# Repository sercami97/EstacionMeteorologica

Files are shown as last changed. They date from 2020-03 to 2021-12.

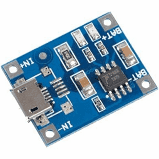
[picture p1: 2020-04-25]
Documentacion/img/tp.png

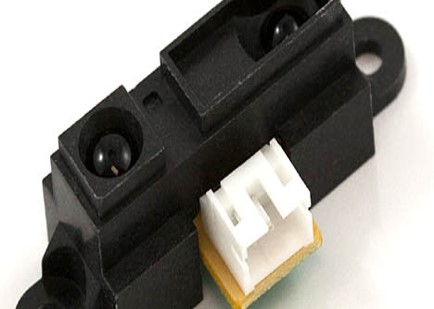
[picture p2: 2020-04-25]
Documentacion/img/sharp.jpg

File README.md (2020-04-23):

# Estacion Meteorológica Inteligente de Bajo Costo

El objetivo del proyecto es diseñar una estación meteorológica inteligente. Esto es, que sea capaz de usar protocolos de IoT para el almacenamiento de los datos en un servidor remoto y ser autosostenible (Energía solar). Además, se espera que los diseños sean fácilmente replicables y tengan un bajo costo. Esto con el objetivo de ser más acesible para las comunidades campesinas y lograr un mayor impacto.

## Comenzando
Descarga o clona el repositorio a tu maquina local. En la capeta ../CodigoArduino/DATA_SERVIDOR_NSM encontrarán el codigo fuente del proyecto (Arduino). Por otro lado, en la carpeta ../PCB/LATEST/PCB_final se encuentran los archivos pertinentes al diseño de la PCB del proyecto. Dentro de esta misma carpeta, en ../GerberSleep se encuentran los archivos gerber listos para mandar a producción. Finalmente, en ../Diseños3D se encuentran los archivos de los diseños 3D desarrollados para la estructura de la estación. 

### Pre-requisitos
Es necesario tener instalados los siguientes sowftware para acceder a los archivos del proyecto:
- Arduino
- KiCad EDA
- Autodesk Inventor
- Libería de Arduino "DHT.h" https://github.com/adafruit/DHT-sensor-library/archive/master.zip
- Libería de Arduino "Arduino.h"
- Libería de Arduino "Wire.h"
- Libería de "ArduinoSoftwareSerial.h"
- Libería de Arduino "DS3232RTC.h" https://github.com/JChristensen/DS3232RTC

### Instalación
Para contar con un prototipo del proyecto debes:
- Imprimir, soldar y armar PCB (En la wiki se describe con mejor detalle como hacer esto junto con los componentes necesarios).
- Imprimir y replicar piezas 3D (En la wiki se describe con mejor detalle como hacer esto junto con los materiales necesarios).
- Armar estación (En la wiki se describe con mejor detalle como hacer esto junto con las piezas necesarias).

### Ejecutando pruebas

#### 1. Codigo Arduino
Para probar la funcionalidad del codigo de arduino, ubíquese en la carpeta ../CodigoArduino/DATA_SERVIDOR_NSM y ejecute el archivo DATA_SERVIDOR_NSM.ino con Arduino. Compila el programa en 'programa' -> 'Verificar/Compilar'. Verificar que no aparezca ningun error en la consola de salida.

#### 2. PCB
Para probar la funcionalidad de la PCB es necesario hacer pruebas de continuidad entre los nodos de la misma. Para esto, puedes usar un multimetro. Si todo está correcto, se puede pasar conectar los componentes y  alimentar la estación con su respectiva batería de litio. 

#### 4. Arduino + PCB
Una vez alimentada la PCB, puede conectar el arduino pro-mini a su ordenador haciendo uso de un cable y módulo FTDI. Ejecute el programa en Arduino y verifique que la placa en 'Herramientas' -> 'Placa' sea Arduino pro mini. Luego, suba el programa en 'Programa' -> 'Subir' y abra el serial en 'Herramientas' -> 'Monitor Serie'. Deberian comenzar a aparecer mensajes que indican la correcta ejecución del código.

#### 5. Funcionalidad
Configure los intervalos de medición de la estación y verifique la funcionalidad de los mensajes en el servidor: http://datos-env.iafjn3xg9q.us-east-1.elasticbeanstalk.com/datos/new/innovandes

#### 6. Estación Completa
Una vez verificados los pasos anteriores, se puede proceder a armar la estación completa con los diseños 3D. Armela y haga nuevamente la prueba del punto 5.

### Construido con
- Arduino
- KiCad EDA
- Autodesk Inventor

### Wiki 
Visita nuestra Wiki https://github.com/sercami97/EstacionMeteorologica/wiki para obtener mas información sobre el dearrollo y cómo utilizar este proyecto.

### Autores
- Iguarán Jorge - Diseños electrónicos y PCB 
- Rodriguez David - Código Arduino y Diseños electrónicos
- Sanabria Sergio - Diseños 3D y replicabilidad

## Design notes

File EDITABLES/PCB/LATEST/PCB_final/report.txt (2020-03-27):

Annotated GND as #PWR015
Annotated WaterLevel as WL1
Annotated StepUpUV3 as SU1
Annotated SIM800L as SIM1
Annotated R as R2
Annotated R as R1
Annotated MicroSdAdapter as Micro_sd1
Annotated DS3231 as DS1
Annotated DHT22 as DHT1
Annotated pro_mini_arduino as APM1
Annotated GND as #PWR019
Annotated VCC as #PWR018
Annotated GND as #PWR017
Annotated VCC as #PWR016
Annotated VCC as #PWR01
Annotated VCC as #PWR014
Annotated GND as #PWR013
Annotated VCC as #PWR012
Annotated VCC as #PWR011
Annotated GND as #PWR010
Annotated GND as #PWR09
Annotated VCC as #PWR08
Annotated GND as #PWR07
Annotated VCC as #PWR06
Annotated VCCQ as #PWR05
Annotated GND as #PWR04
Annotated GND as #PWR03
Annotated VCC as #PWR02

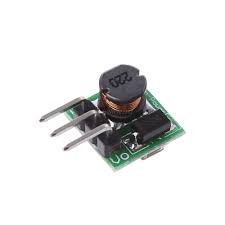
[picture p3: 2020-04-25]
Documentacion/img/su.jpg

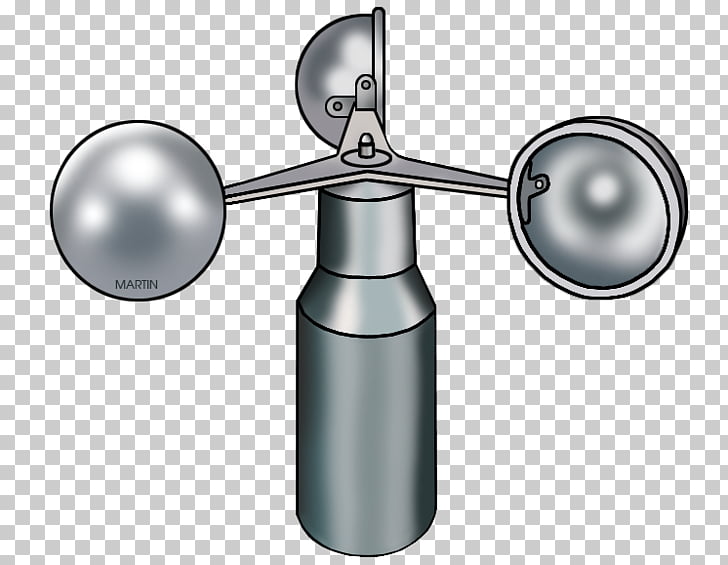
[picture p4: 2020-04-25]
Documentacion/img/anemometro.jpg

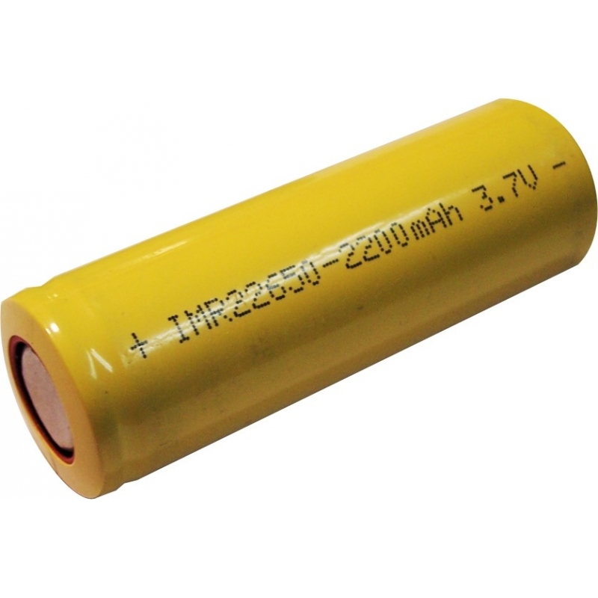
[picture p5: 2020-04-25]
Documentacion/img/bateria.jpg

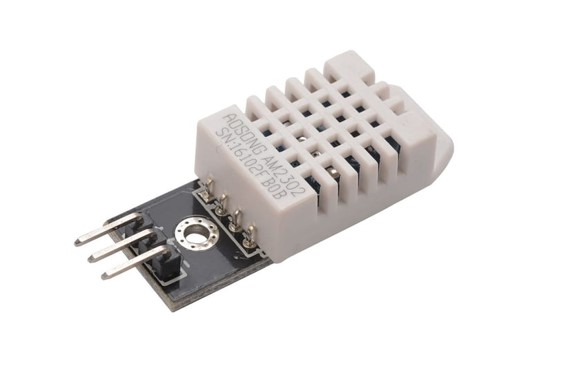
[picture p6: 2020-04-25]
Documentacion/img/dht.jpg

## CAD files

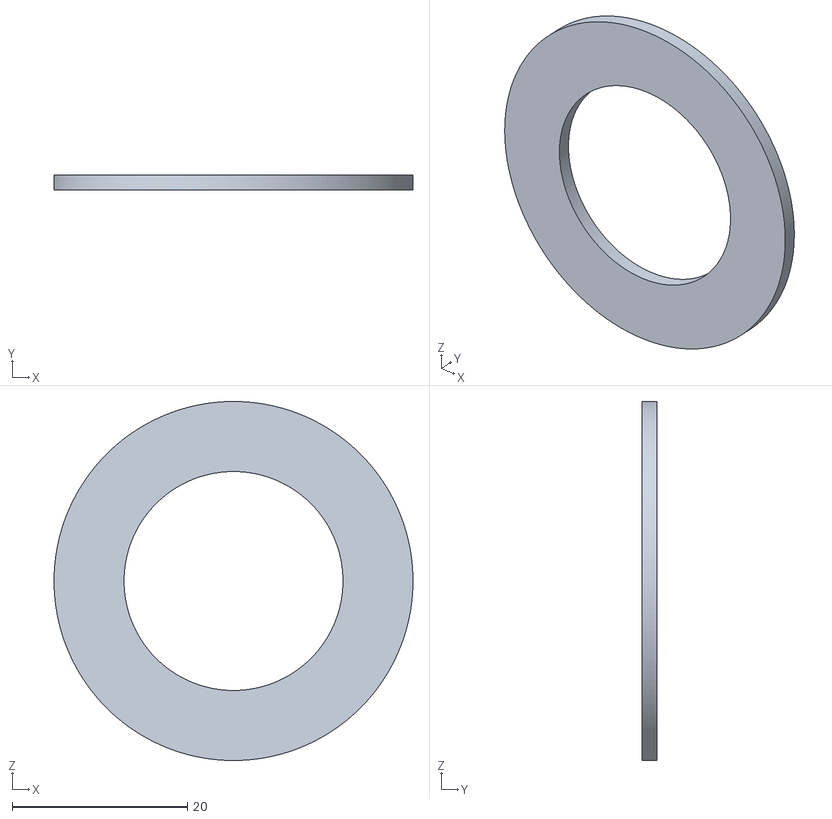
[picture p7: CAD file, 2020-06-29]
Diseños3D/STL/VIENTO/9JUN20/DireccionComplemento.stl
41.0 x 1.70 x 41.0

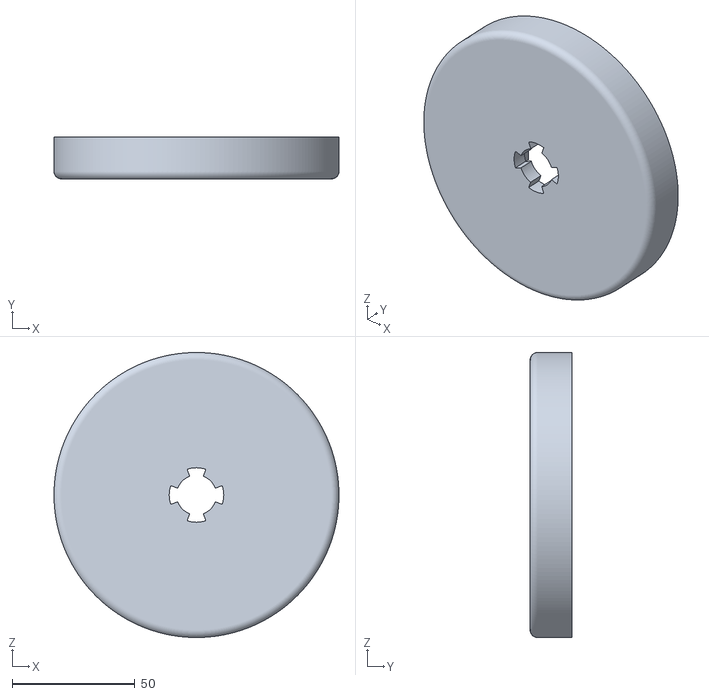
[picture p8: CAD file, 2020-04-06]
Diseños3D/STL/VIENTO/BaseHumedadDireccion.stl
116.0 x 17.0 x 116.0

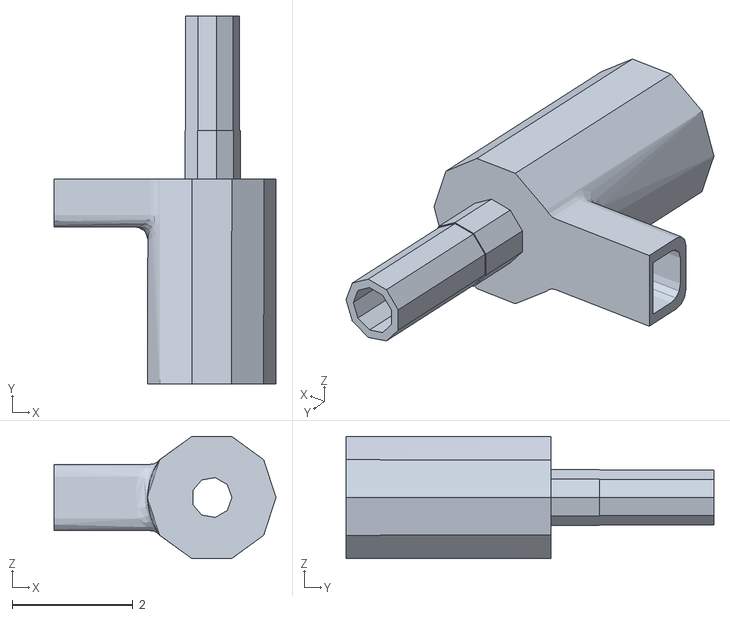
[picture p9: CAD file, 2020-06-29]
Diseños3D/STL_PROTOTIPO/Febrero27/Base Anemometro.stl
3.68 x 6.10 x 2.03

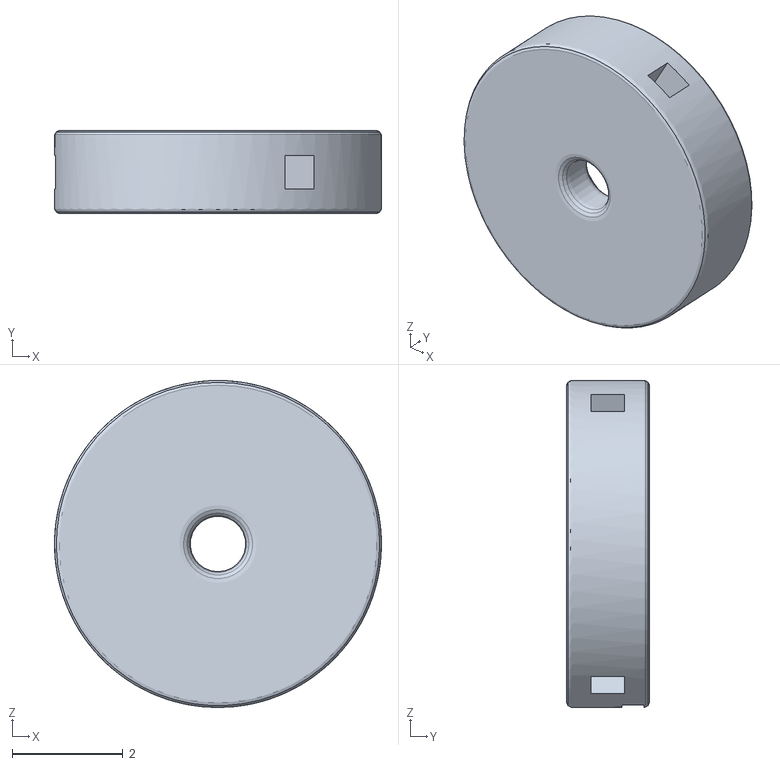
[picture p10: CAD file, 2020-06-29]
Diseños3D/STL_PROTOTIPO/Test/BasePaletas.stl
5.90 x 1.50 x 5.90

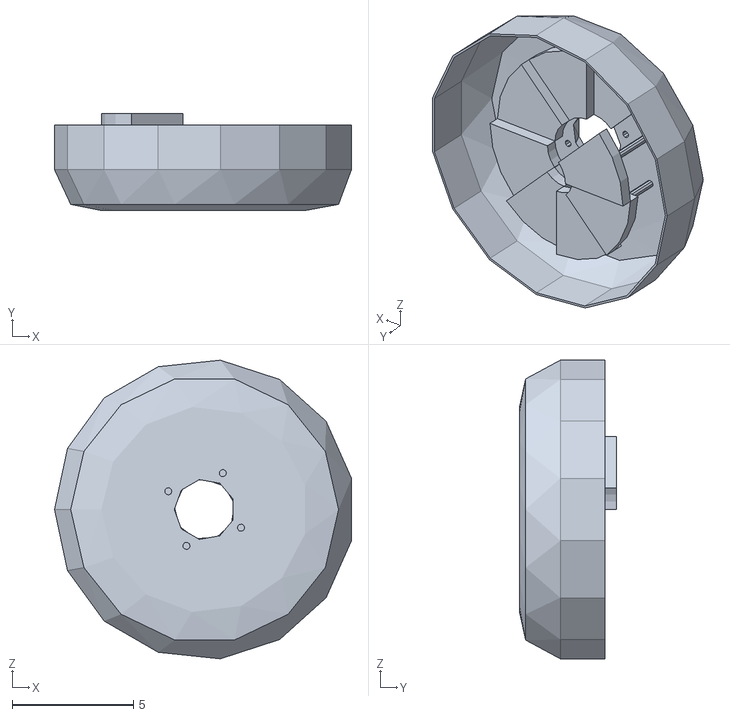
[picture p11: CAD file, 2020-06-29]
Diseños3D/STL_PROTOTIPO/V2/DesnivelSharp.stl
12.2 x 4.00 x 12.3

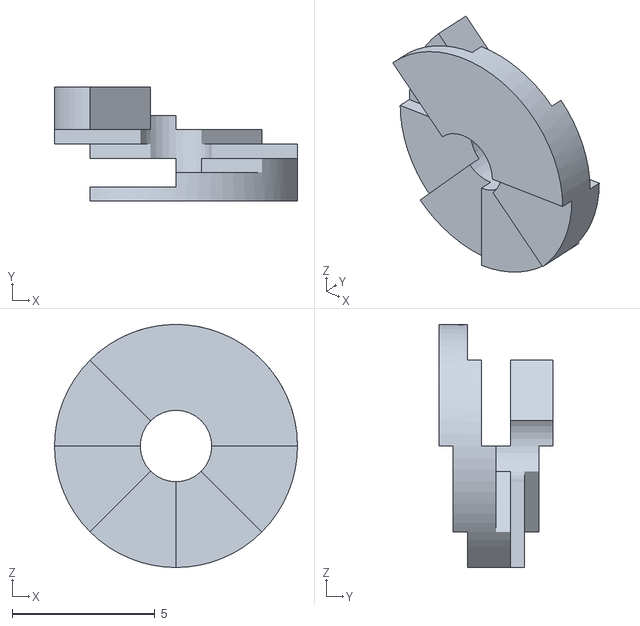
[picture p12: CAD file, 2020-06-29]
Diseños3D/STL_PROTOTIPO/V2/V/DesnivelSharp.stl
8.50 x 4.00 x 8.50

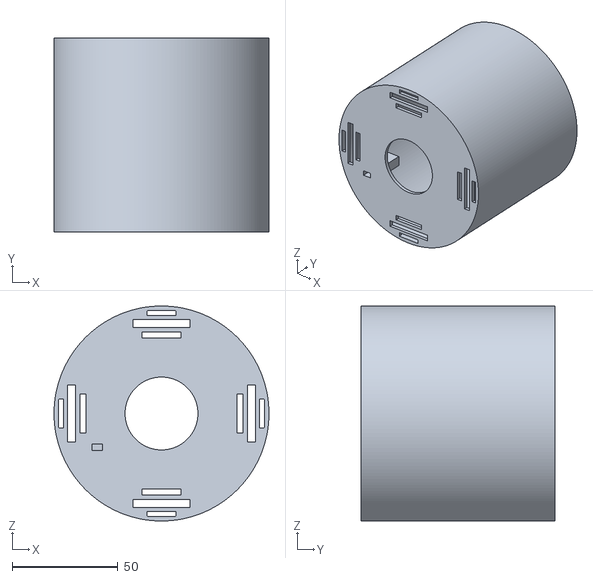
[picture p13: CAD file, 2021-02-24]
EDITABLES/3D/VersionFinal/Pluviografo/BasePlu.stl
101.8 x 92.0 x 101.8

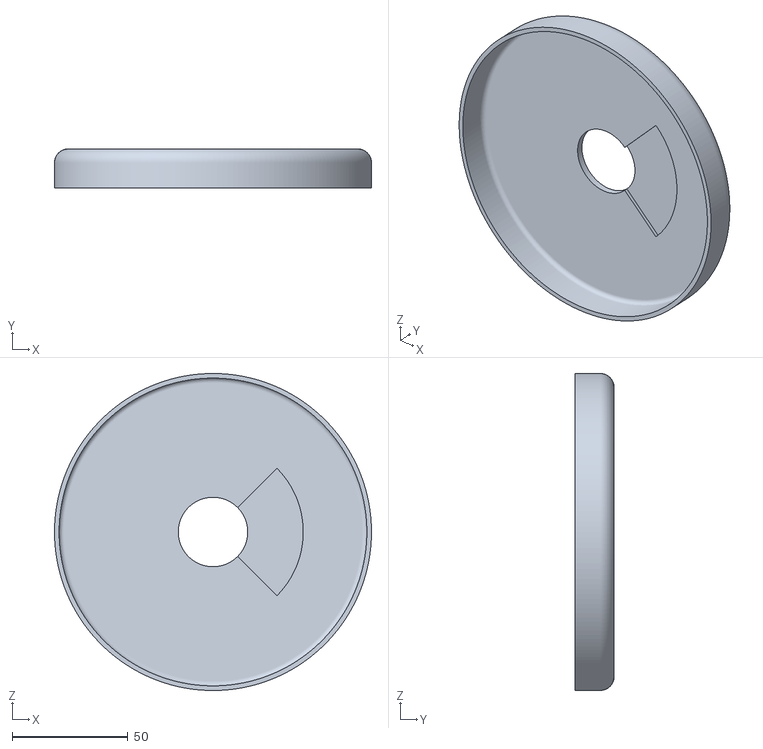
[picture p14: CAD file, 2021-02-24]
EDITABLES/3D/VersionFinal/STL/10Oct/DireccionBase.stl
137.0 x 17.0 x 137.0

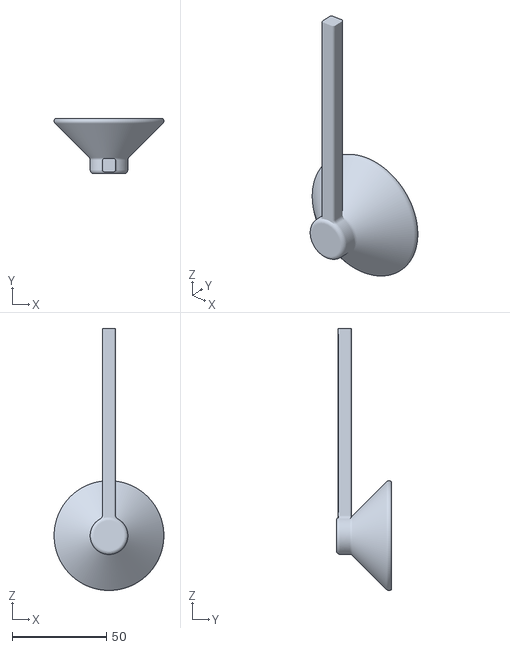
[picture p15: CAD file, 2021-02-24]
EDITABLES/3D/VersionFinal/STL/7Agosto/PaletaCono.stl
58.3 x 29.4 x 139.2

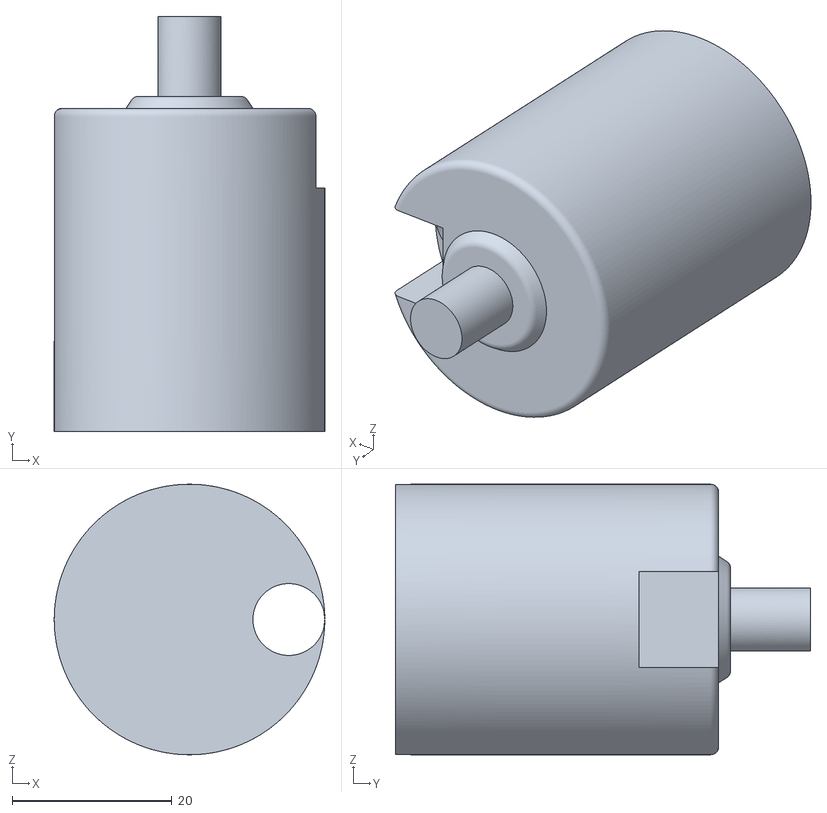
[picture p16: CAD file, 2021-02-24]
EDITABLES/3D/VersionFinal/STL/8Agosto/BaseEje.stl
33.9 x 52.0 x 33.9

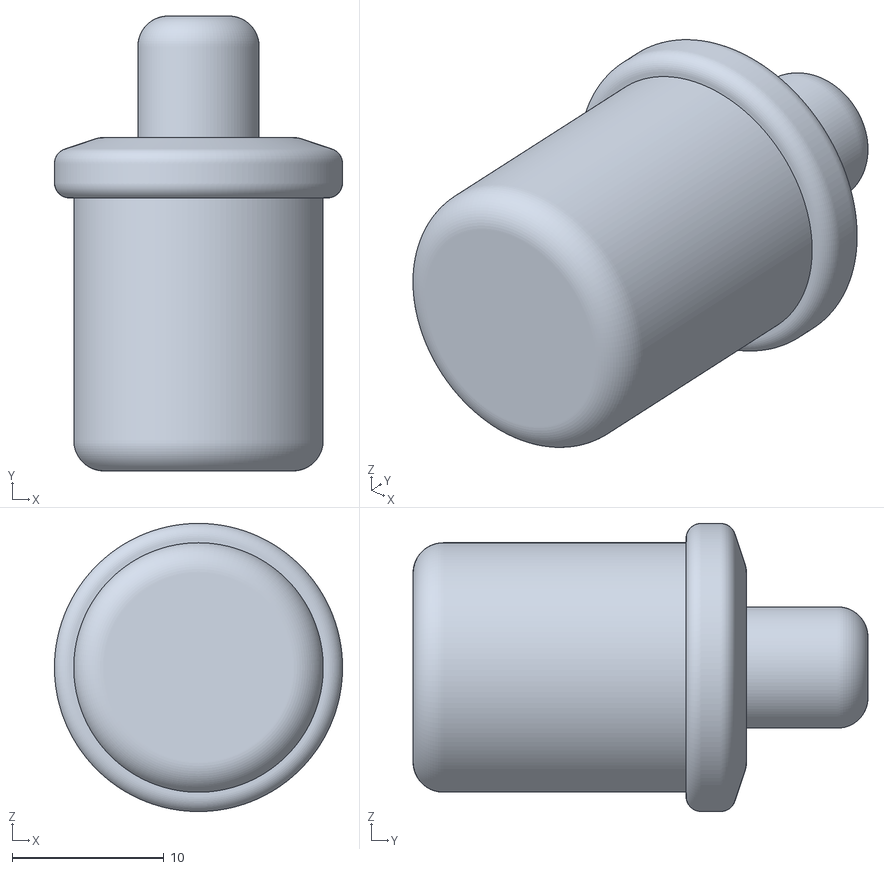
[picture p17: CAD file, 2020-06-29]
Diseños3D/STL/VIENTO/9JUN20/ConexionDireccionTop.stl
19.0 x 30.0 x 19.0

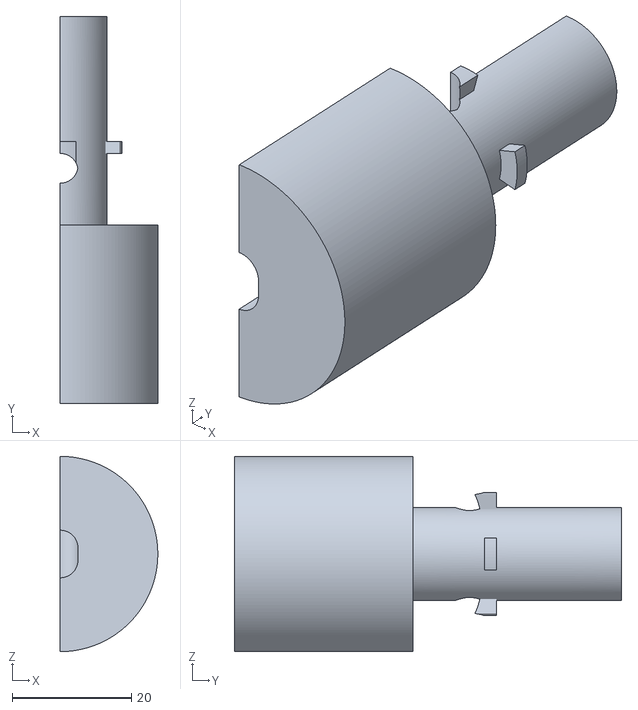
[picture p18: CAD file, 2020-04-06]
Diseños3D/STL/VIENTO/SoportePulgadaMitad.stl
16.4 x 65.0 x 32.8

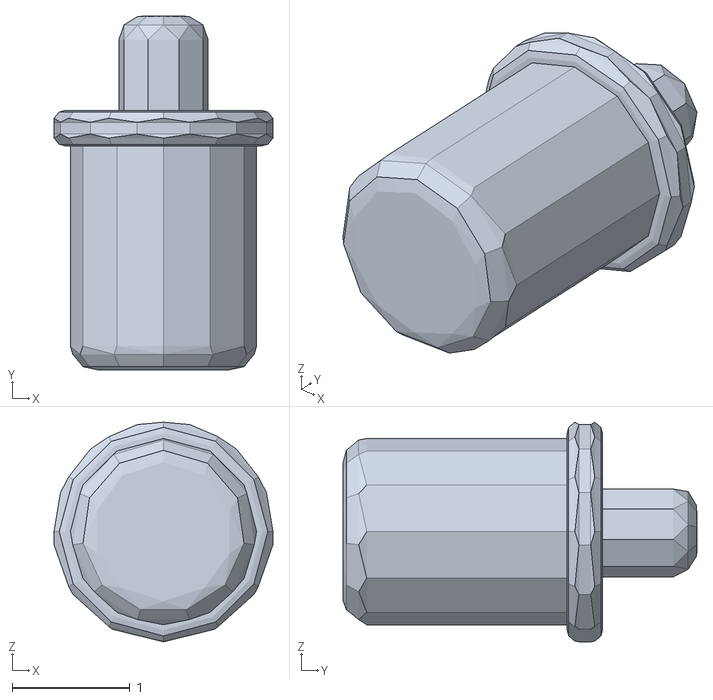
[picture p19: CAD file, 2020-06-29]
Diseños3D/STL_PROTOTIPO/Febrero27/ConexionDireccionTop.stl
1.86 x 3.00 x 1.86

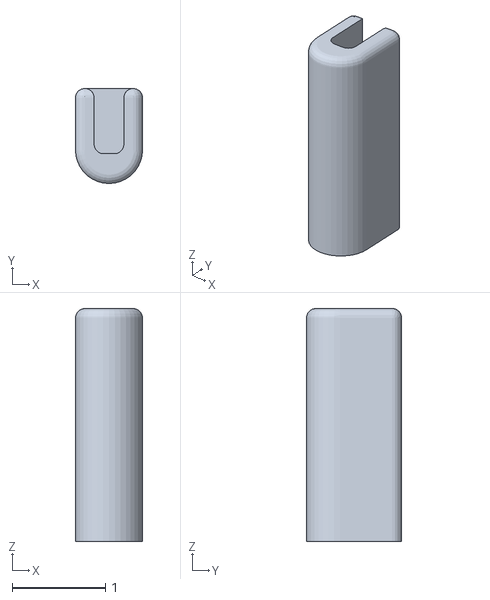
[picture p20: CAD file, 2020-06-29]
Diseños3D/STL_PROTOTIPO/Test/CajonReed.stl
0.72 x 1.02 x 2.50

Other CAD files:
Diseños3D/STL_PROTOTIPO/V2/ConexionDireccionBottom.stl
Diseños3D/STL_PROTOTIPO/V2/V/DesnivelSharp2.stl
EDITABLES/3D/VersionFinal/STL/7Agosto/Direccion.stl
EDITABLES/3D/VersionFinal/STL/8Agosto/CajonInf.stl
Diseños3D/STL/VIENTO/9JUN20/DireccionBase.stl
Diseños3D/STL/VIENTO/9JUN20/DireccionEscalones.stl
Diseños3D/STL/VIENTO/9JUN20/PruebaRodamiento.stl
Diseños3D/STL/VIENTO/9JUN20/SoportePulgadaMitad.stl
Diseños3D/STL/VIENTO/PlatoHumedadDireccion.stl
Diseños3D/STL_PROTOTIPO/Febrero27/BasePaletas.stl
Diseños3D/STL_PROTOTIPO/Febrero27/CajonReed.stl
Diseños3D/STL_PROTOTIPO/Febrero27/spherewind.stl
Diseños3D/STL_PROTOTIPO/Test/Base Anemometro.stl
Diseños3D/STL_PROTOTIPO/Test/ConexionDireccionBottom.stl
Diseños3D/STL_PROTOTIPO/Test/ConexionDireccionTop.stl
Diseños3D/STL_PROTOTIPO/Test/DesnivelSharp2.stl
Diseños3D/STL_PROTOTIPO/Test/Direccion.stl
Diseños3D/STL_PROTOTIPO/V1/Base Anemometro.stl
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

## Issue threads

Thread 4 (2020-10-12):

Mejoras3D

sercami97, 2020-10-12:
Piso mas grueso para pluviografo base.
No curvear (fillet) eje viento mitad. No se puede unir a 90 grados con base HumTempDir

sercami97, 2020-10-12:
Hacer piezas con vertederos

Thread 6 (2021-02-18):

PCB Design

sercami97, 2021-02-18:

sercami97, 2021-02-18:
RTCModule too close.
Pista Power SIM800L mas gruesa
Despejar arduino micro conectar ftdi

sercami97, 2021-02-25:
RST pin SIM800L

sercami97, 2021-04-27:
60mil trace width

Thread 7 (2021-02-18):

Design

sercami97, 2021-02-18:
Charger RTCModule
SIM800L not enough power routes width & 3.4v

sercami97, 2021-02-20:
DTR interfiere con inteerups sleep mode

sercami97, 2021-02-23:
Conector FTDI fast test

sercami97, 2021-02-23:
Easy look for states led

sercami97, 2021-02-26:
PIN reser arduino

sercami97, 2021-02-26:
Acomodar capacitores cerca sim800l

sercami97, 2021-02-26:
Alimentacion sim800l

sercami97, 2021-03-01:
TP4056. Not charging when voltage is under 2.9v due mosfet.

sercami97, 2021-03-16:
Sensores y Metal expuestos al ambiente.

sercami97, 2021-03-16:
Progamación desde WIFI

sercami97, 2021-04-27:
diodes foward voltage froms voltage divisor

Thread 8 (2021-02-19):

Codigo Arduino

sercami97, 2021-02-19:
Manejar errores de red SIM800L

sercami97, 2021-02-23:
Libreria para ATcommands

sercami97, 2021-02-28:
Modulo estancado sleep mode cuando el envio se demora determinado tiempo. Hace que se le ponga una alarma al rtc de un tiempo que ya paso, por lo cual nunca manda el interrupt.

sercami97, 2021-03-06:
En vez de mandarlo a state DATOS cuando RESET SIM no funciona por primera o segunda vez, hacerlo dormir y que despues vuelva a intentar enviar el conjunto de DATOS anterior. Sino funciona, al igual que actualmente, reset arduino.

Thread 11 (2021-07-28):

Julio2021

sercami97, 2021-07-28:
La cadena de cracteres se reinicia en la 3ra toma de datos. Cuando se llega a las 5 tomas de datos se resetea si el sim800l esta conectado.

sercami97, 2021-07-28:
BUtton portector ic gnd de bateria. Al principio la abteria no se coencta con gnd por proteccion. Para encender mas facil la estacion sin cargador presente.

sercami97, 2021-07-29:
Transistor reset

sercami97, 2021-07-29:
No low power consumption needed for SIM800l. Maybe no reset sim800l att all.

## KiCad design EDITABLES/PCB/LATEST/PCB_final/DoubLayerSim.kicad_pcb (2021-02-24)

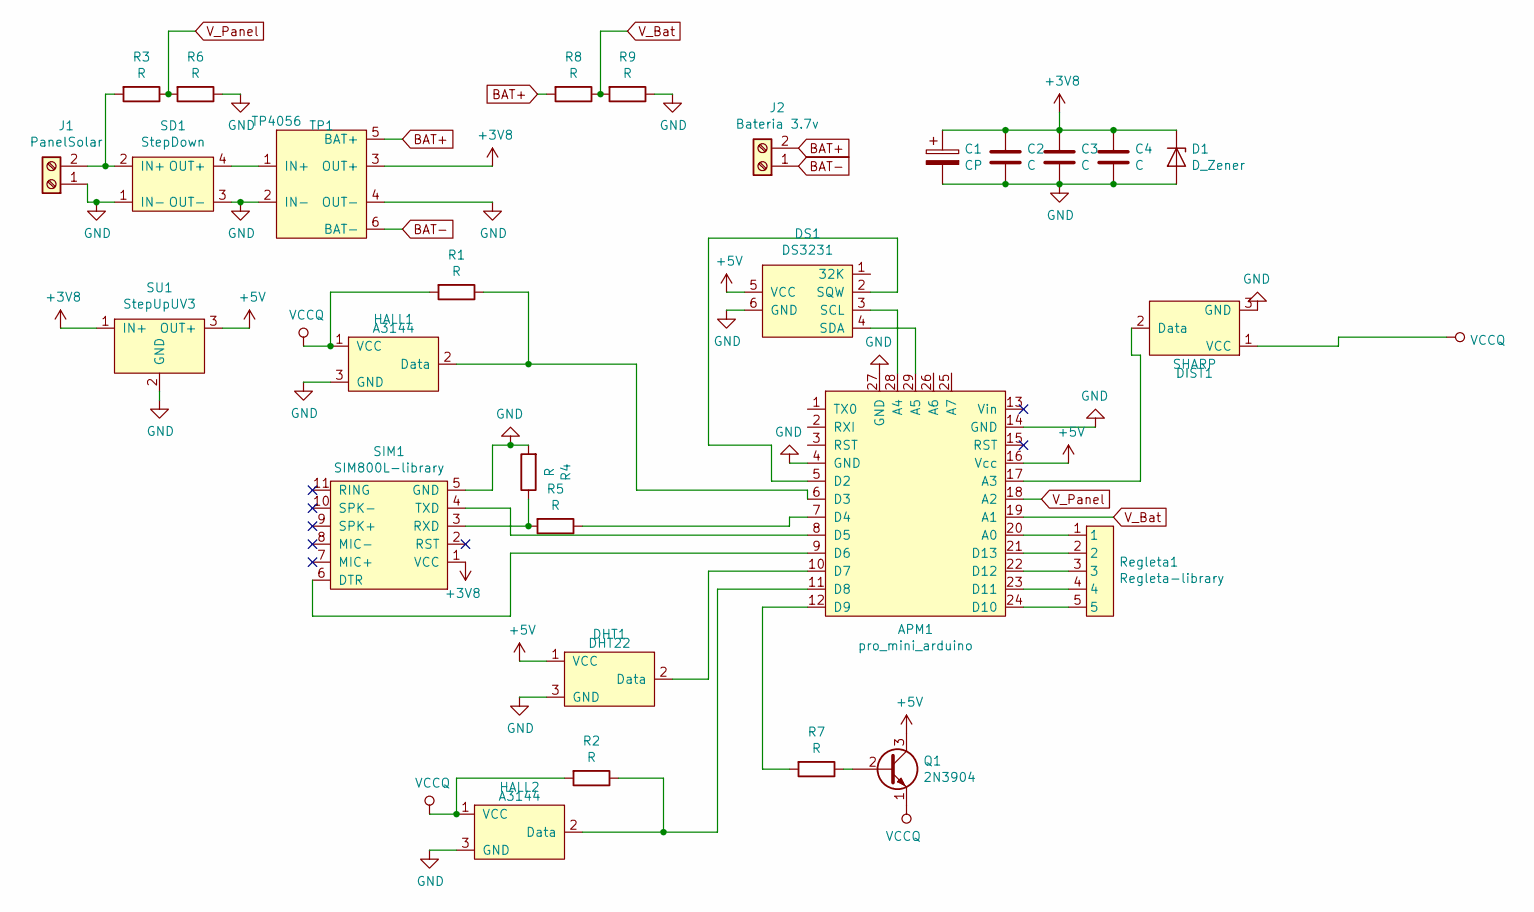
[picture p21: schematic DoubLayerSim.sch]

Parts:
APM1: pro_mini_arduino; mini_pro
C1: CP; CP_Radial_D10.0mm_P5.00mm
C2, C3, C4: C; C_Disc_D4.3mm_W1.9mm_P5.00mm
D1: D_Zener; D_T-1_P5.08mm_Horizontal
DHT1: DHT22
DIST1: SHARP; Hall
DS1: DS3231
HALL1, HALL2: A3144; Hall
J1: PanelSolar; TerminalBlock_bornier-2_P5.08mm
J2: Bateria 3.7v; TerminalBlock_bornier-2_P5.08mm
Q1: 2N3904; TO-92_Inline
R1, R2, R3, R4, R5, R6, R7, R8, R9: R; ResistorPCB
Regleta1: Regleta-library; PinHeader_1x05_P2.54mm_Vertical
SD1: StepDown; MP1584
SIM1: SIM800L-library; SIM800L
SU1: StepUpUV3; SU_U3V
TP1: TP4056; TP4056Pro

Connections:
+3V8: C1.1, C2.1, C3.1, C4.1, D1.1 (K), SIM1.1 (VCC), SU1.1 (IN+), TP1.3 (OUT+)
+5V: APM1.16 (Vcc), DHT1.1 (VCC), DS1.5 (VCC), Q1.3 (C), SU1.3 (OUT+)
BAT+: J2.2, R8.2, TP1.5 (BAT+)
BAT-: J2.1, TP1.6 (BAT-)
GND: APM1.4 (GND), APM1.14 (GND), APM1.27 (GND), C1.2, C2.2, C3.2, C4.2, D1.2 (A), DHT1.3 (GND), DIST1.3 (GND), DS1.6 (GND), HALL1.3 (GND), HALL2.3 (GND), J1.1, R4.2, R6.1, R9.1, SD1.1 (IN-), SD1.3 (OUT-), SIM1.5 (GND), SU1.2 (GND), TP1.2 (IN-), TP1.4 (OUT-)
unnamed: APM1.5 (D2), DS1.2 (SQW)
unnamed: APM1.6 (D3), HALL1.2 (Data), R1.1
unnamed: APM1.7 (D4), R5.1
unnamed: APM1.8 (D5), SIM1.4 (TXD)
unnamed: APM1.9 (D6), SIM1.6 (DTR)
unnamed: APM1.10 (D7), DHT1.2 (Data)
unnamed: APM1.11 (D8), HALL2.2 (Data), R2.1
unnamed: APM1.12 (D9), R7.2
unnamed: APM1.17 (A3), DIST1.2 (Data)
unnamed: APM1.20 (A0), Regleta1.1
unnamed: APM1.21 (D13), Regleta1.2
unnamed: APM1.22 (D12), Regleta1.3
unnamed: APM1.23 (D11), Regleta1.4
unnamed: APM1.24 (D10), Regleta1.5
unnamed: APM1.28 (A4), DS1.3 (SCL)
unnamed: APM1.29 (A5), DS1.4 (SDA)
unnamed: J1.2, R3.2, SD1.2 (IN+)
unnamed: Q1.2 (B), R7.1
unnamed: R4.1, R5.2, SIM1.3 (RXD)
unnamed: SD1.4 (OUT+), TP1.1 (IN+)
VCCQ: DIST1.1 (VCC), HALL1.1 (VCC), HALL2.1 (VCC), Q1.1 (E), R1.2, R2.2
V_Bat: APM1.19 (A1), R8.1, R9.2
V_Panel: APM1.18 (A2), R3.1, R6.2

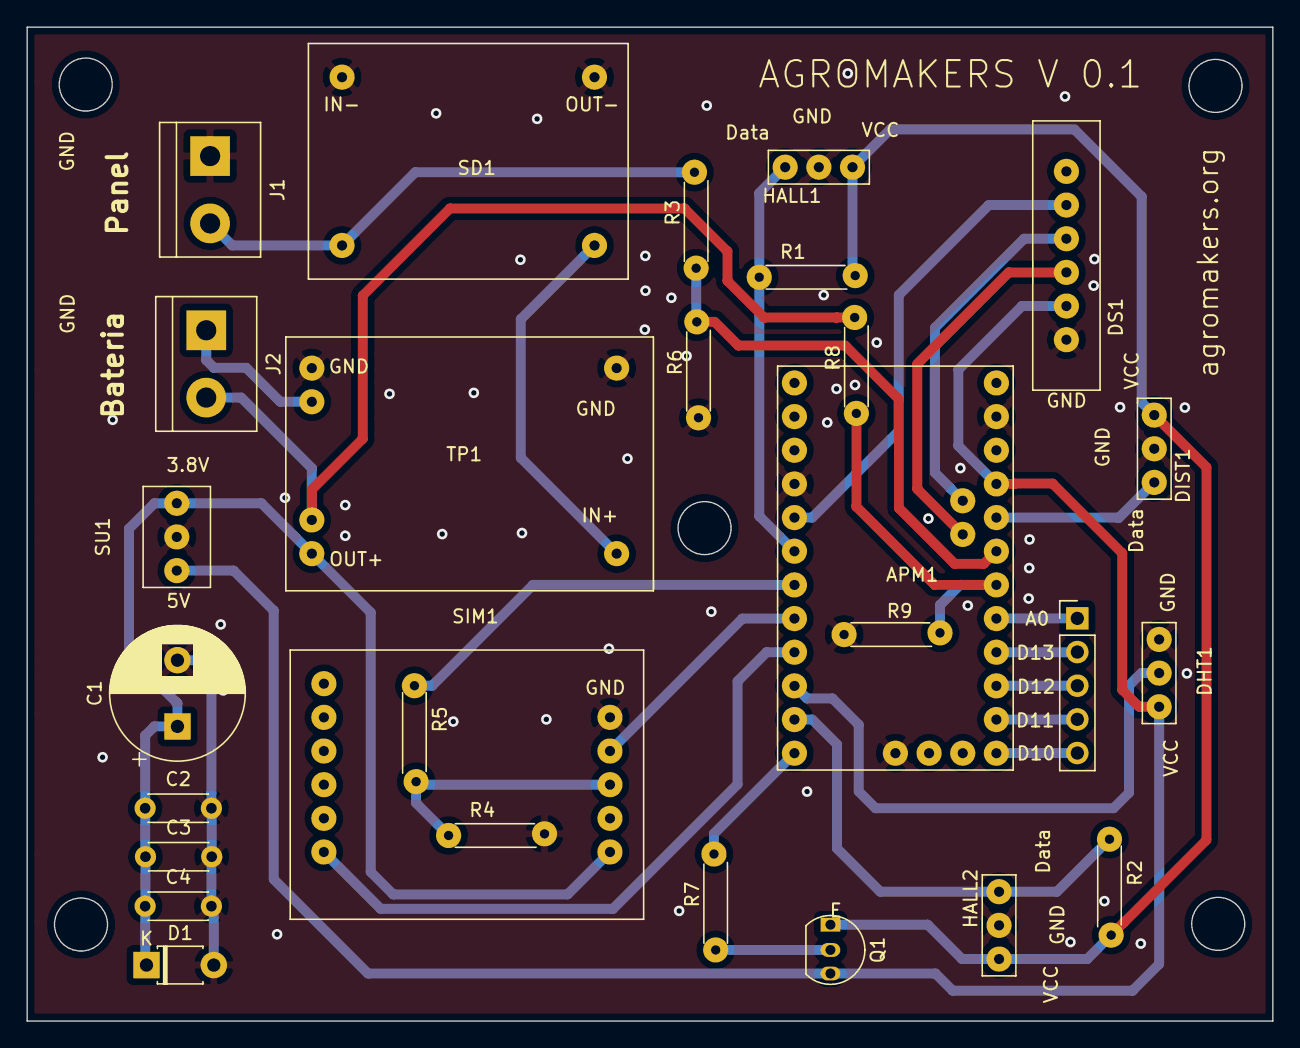
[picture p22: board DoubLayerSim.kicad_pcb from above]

Board: 2 copper layers, 94.0 x 75.0 mm, 28 parts (0 on the bottom side), 28 nets.

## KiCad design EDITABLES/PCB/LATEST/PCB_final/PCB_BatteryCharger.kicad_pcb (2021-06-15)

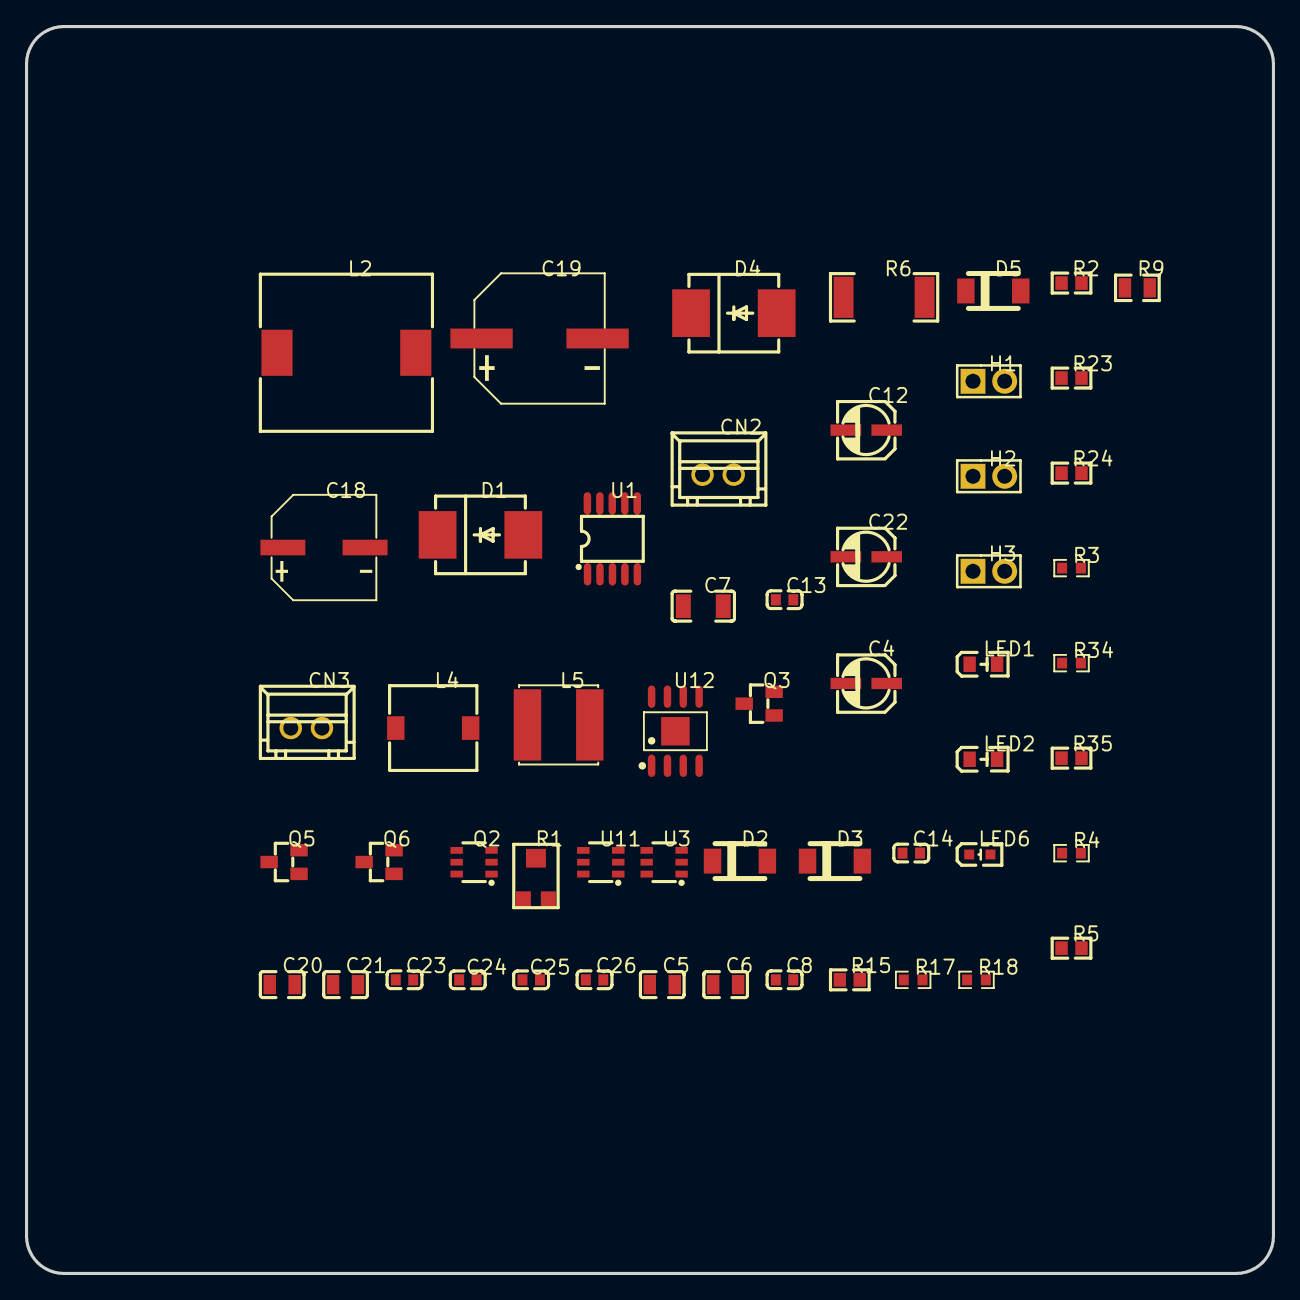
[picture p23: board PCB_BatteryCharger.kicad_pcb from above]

Board: 2 copper layers, 100.0 x 100.0 mm, 55 parts (0 on the bottom side), 38 nets, no tracks yet.

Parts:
C4, C12, C22: 10uF; CAP-SMD_BD4.0-L4.3-W4.3-RD
C5, C6, C20, C21: 4.7uF; C0805
C7: 220nF; C1206
C8, C13, C23, C26: 100nF; C0603
C14: 470nF; C0603
C18: 470uF; CAP-SMD_BD8.0-L8.3-W8.3-FD
C19: 330uF; CAP-SMD_BD10.0-L10.3-W10.3-FD
C24: 33nF; C0603
C25: 10nF; C0603
CN2, CN3: XH-2A; CONN-TH_XH-2A
D1, D4: SS34; SMC_L7.1-W6.2-LS8.1-RD
D2: 0; SOD-128_L3.7-W2.5-LS4.7-RD
D3, D5: PMEG3020EP,115; SOD-128_L3.7-W2.5-LS4.7-RD
H1, H2, H3: CURR; HDR-TH_2P-P2.54-V-F
L2: 82uH; IND-SMD_L13.8-W12.6_SMMS1360
L4: 22uH; IND-SMD_L7.0-W6.8
L5: 47uH; IND-SMD_L6.0-W6.0
LED1: RED; LED0805-RD
LED2: YELLOW; LED0805-RD
LED6: BLUE; LED0603-R-RD
Q2: FS8205; SOT-23-6_L2.9-W1.6-P0.95-LS2.8-BR
Q3, Q5, Q6: AO3401A; SOT-23_L2.9-W1.3-P1.90-LS2.4-BR
R1: 15K; RES-ADJ-SMD_VG039NCHXTB153
R2, R35: 2K; R0603
R3: 100K; R0603
R4: 5.6K; R0603
R5, R15, R23: 1K; R0603
R6: 0.05; R2512
R9: 120; R0805
R17: 76.8K; R0603
R18: 16K; R0603
R24: 7.5K; R0603
R34: 100; R0603
U1: CN3791; SSOP-10_L4.9-W3.9-P1.00-LS6.0-BL
U3: FS312F-G; SOT-23-6_L2.9-W1.6-P0.95-LS2.8-BR
U11: MT3608; SOT-23-6_L2.9-W1.6-P0.95-LS2.8-BR
U12: TD1519AMR; SOP-8_L4.9-W3.9-P1.27-LS6.0-BL-EP

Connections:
+5V: C21.2, C22.1, D3.1, Q6.3, R24.2
BAT: C20.2, L4.1, U11.4, U11.5
BAT+: C4.1, C6.2, H2.1, R6.2, R34.2, U1.7
BAT-: C13.2, CN3.2, Q2.3, U3.6
BS: C25.1, U12.1
C24_1: C24.1, R4.2
CN2_1: CN2.1, D2.2
COMP: C24.2, U12.6
D1_2: D1.2, D4.2, L2.1
D4_1: D4.1, Q5.3
EN: R3.2, U12.7
GND: C4.2, C5.1, C6.1, C7.1, C12.2, C14.1, C18.2, C19.2, C20.1, C21.1, C22.2, C23.1, C26.1, CN2.2, D1.1, LED6.2, Q2.1, R2.1, R4.1, R15.2, R18.1, R23.1, U1.2, U11.2, U12.4, U12.9
H1_2: D2.1, H1.2
H2_2: CN3.1, H2.2
L4_2: D3.2, L4.2, U11.1
LED6_1: LED6.1, R35.1
MPPT: R1.3, R15.1, U1.6
Q6_2: Q3.2, Q6.2
R5_1: LED1.2, LED2.2, R5.1
R9_1: C7.2, R9.1
R23_2: R23.2, R24.1, U11.3
SS: C23.2, U12.8
SW: C25.2, L5.1, U12.3
U1_1: C8.2, U1.1
U1_3: LED1.1, U1.3
U1_4: LED2.1, U1.4
U1_5: R9.2, U1.5
U1_8: L2.2, R6.1, U1.8
U1_10: Q5.1, U1.10
U3_1: Q2.4, U3.1
U3_2: R2.2, U3.2
U3_3: Q2.6, U3.3
U3_5: C13.1, R34.1, U3.5
U12_5: R17.1, R18.2, U12.5
VOUT: D5.1, Q3.3
V_SOL: C5.2, C8.1, C12.1, C14.2, H1.1, Q5.2, R1.1, R5.2
V_SOLAR: C19.1, C26.2, Q3.1, Q6.1, R3.1, U12.2
V_SOL_5V: C18.1, D5.2, L5.2, R17.2

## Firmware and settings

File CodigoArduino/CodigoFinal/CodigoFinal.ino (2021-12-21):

#include "Arduino.h"
#include <SoftwareSerial.h>
#include "DHT.h" // Libreria DHT de Adafruit para DHT 11 o DHT 22 https://github.com/adafruit/DHT-sensor-library/archive/master.zip
#include <avr/sleep.h> //Libreria avr que contiene los metodos que controlan el modo sleep
#include <DS3232RTC.h>  //Libreria RTC https://github.com/JChristensen/DS3232RTC
#include "SIM800L.h"

#define SIM800_RX_PIN 5
#define SIM800_TX_PIN 4
#define SIM800_RST_PIN 10

const char APN[] = "internet.comcel.com.co";
const char USR[] = "comcel";
const String URL = "https://eco.agromakers.org/api/r_v?id=2020080427&tramo=";
const String URL2 = "https://eco.agromakers.org/api/r_v?id=2020080427&tramo=";

SIM800L* sim800l;


//------------------------HALL---------------------
#define  hall_an 3  //Pin Anemometro (Vel. Viento)
#define  hall_pluv1 8 //Pin Anemometro (Pluviografo1)

uint8_t hallCounter = 0;   //Contador tic tocs anemometro
uint8_t hallState = 0;         //Estado actual del sensor efecto hall anemometro (HIGH,LOW)
uint8_t lastHall = 0;     //Estado previo del sensor efecto hall anemometro (HIGH,LOW)
uint8_t lLastHall = 0;     //Estado previo del sensor efecto hall anemometro (HIGH,LOW)
uint8_t lLLastHall = 0;     //Estado previo del sensor efecto hall anemometro (HIGH,LOW)

uint8_t hallCounter1 = 0;   //Contador tic tocs ´pluviografo
uint8_t hallState1 = 0;      //Estado actual del sensor efecto hall pluviografo (HIGH,LOW)
uint8_t lastHall1 = 0;    //Estado previo del sensor efecto hall pluviografo (HIGH,LOW)
uint8_t lLastHall1 = 0;     //Estado previo del sensor efecto hall anemometro (HIGH,LOW)
uint8_t lLLastHall1 = 0;     //Estado previo del sensor efecto hall anemometro (HIGH,LOW)

int tiempo_hall = 60000;

//------------------ END HALL --------------

//---------------- SLEEP MODE & RTC ---------------
//Variables 
//Variables de tiempo para el sensado del anemometro y el pluviografo
unsigned long starttime;
unsigned long new_endtime = 0;
int len;

//Numero de tomas y Sleep Mode
#define transistor_Pin 9   //Pin del transistor
#define interruptPin 2 //Pin de interrupcion para despertar el arduino

const uint8_t time_interval = 15; //Intervalo de tiempo para la toma de datos
const uint8_t num_ciclos = 5; //Definir numero de tomas previas al envío (tomar 6 como valor máximo para evitar problemas de inestabilidad)

uint8_t ciclo = 0; 

uint8_t last_wake_up_min; //Variable de tiempo en el que se despierta el arduino
uint8_t last_wake_up_hour; //Variable de tiempo en el que se despierta el arduino

uint8_t wake_up_min; //Variable de tiempo en el que se despierta el arduino
uint8_t wake_up_hour; //Variable de tiempo en el que se despierta el arduino


bool date_done = true;

//----------------END SLEEP MODE & RTC ---------------


// -------------------- IR -----------------
int WV;
//uint8_t direccion; //Variable de direccion como entero, tomara valores (1-9)

// -------------------- END IR -----------------

// --------------------- DHT ---------------------
#define DHTPIN 7     //Pin donde está conectado el sensor DHT
#define DHTTYPE DHT22   //Sensor DHT22
DHT dht(DHTPIN, DHTTYPE);
uint8_t h;  //Variable de humedad relativa (0-100)
uint16_t temp; //Variable temeperatura grados centigrados

// -------------------- END DHT ---------------

// ---------------- ESTADOS -------------
//Estado
uint8_t state = 1;
uint8_t last_state = 1;
  
const uint8_t DORMIR PROGMEM = 2;
const uint8_t DATOS PROGMEM = 1;
const uint8_t ENVIO PROGMEM = 3;
const uint8_t RESET_SIM PROGMEM = 5;
const uint8_t RESET_ARDU PROGMEM = 6;
const uint8_t ASK_BAT PROGMEM = 7;

const uint16_t MIN_VOLT_BAT = 345;
const uint8_t MIN_VOLT_PAN = 80;

boolean wait = false;

const uint8_t LIMIT_CONT = 35;


// ------------------ END ESTADOS -------------
// --------------SYSTEM VARIABLES -------------
//Outputs
//Strings en donde se almacenan los datos tomados
String finalString;

String msg;

boolean first_init = true;
boolean first_run = true;

uint16_t vol_bat;
uint8_t vol_panel; 

uint8_t cont_rst_sim = 0;

#define RST_ARD 11

const uint16_t MAX_BYTES = 280;

// --------------END SYSTEM VARIABLES -------------


//Que se cuenten envios de rrores pero que siga los siguientes estados. Reset cuando hallan 3 mensajes que no se han enviado.
void setup() {
  digitalWrite(RST_ARD, HIGH);
  delay(200);
  pinMode(RST_ARD, OUTPUT);  
  // Initialize Serial Monitor for debugging
  Serial.begin(9600);
  while(!Serial);

  // Initialize a SoftwareSerial
  SoftwareSerial* serial = new SoftwareSerial(SIM800_RX_PIN, SIM800_TX_PIN);
  serial->begin(9600);
  delay(1000);
   
  // Initialize SIM800L driver with an internal buffer of 200 bytes and a reception buffer of 512 bytes, debug disabled
  //sim800l = new SIM800L((Stream *)serial, SIM800_RST_PIN, 290, 20);

  // Equivalent line with the debug enabled on the Serial
  sim800l = new SIM800L((Stream *)serial, SIM800_RST_PIN, 305, 20, (Stream *)&Serial);
  delay(10000);

  msg.reserve(MAX_BYTES); //Reservar memoria en bytes para la cadena de caracteres de los datos
  delay(1000);

  inicializarPines(); //Inicializar pines sensores efecto hall, dht, interrupt, transistor
  inicializarSM(); //Inicializar Sleep Mode

  delay(5000);
  
  tomaDatos();
  updateVolt();
  if(vol_bat <= MIN_VOLT_BAT and vol_panel <= MIN_VOLT_PAN){
    Serial.println(F("LOW BATTERY UNABLE TO SEND SIM"));
    state = DORMIR;
  }else{
    Serial.println(F("Init Data"));
    tomaDatos();
    delay(1000);
    tomaDatos();
    eliminarUltimoDigitoURL();
    
    if(sendGet(msg)){
      state = DATOS;
      remove_msg();
    }else{
      state = RESET_SIM;
    }
  }
  

}

void loop() {

  switch (state) {
  case DATOS:
    tomaDatos(); //Tomar datos de las variables de interes
//    Serial.println(ciclo);
//    Serial.println(num_ciclos);
    if(ciclo >= num_ciclos){
//    Serial.println(F("IN pre envio"));
      state = ENVIO;
      eliminarUltimoDigitoURL();
      ciclo = 0;
    }else{
      ciclo ++;
      state = DORMIR;
    }
    last_state = DATOS;
    break;
  case ENVIO:
    Serial.println(F("Envio"));
    updateVolt();
    if(vol_bat <= MIN_VOLT_BAT and vol_panel <= MIN_VOLT_PAN){
      Serial.println(F("LOW BATTERY UNABLE TO SEND SIM"));
      state = DORMIR;
      break;
    }
    if(sendGet(msg)==false){
      Serial.println(F("ERROR ENVIO"));
      state = RESET_SIM;
      break;
    }
    remove_msg();
    cont_rst_sim = 0;    
    state = DORMIR; 
    break;
  case DORMIR:
    Going_To_Sleep();
    state = ASK_BAT;
    break;
  case RESET_SIM:
    Serial.println(F("Reset SIM"));
    sim800l->reset();
    delay(5000);
    state = ASK_BAT;
    last_state = RESET_SIM;
    //cont_rst_sim = 0 -> Primer RESET SIM vuelve intentar envio
    //cont_rst_sim = 1 -> Segundo RESET SIM vuelve intentar envio
    //cont_rst_sim = 2 -> Tercer RESET SIM borra envio y vuelve a tomar datos.
    //cont_rst_sim = 3 -> Reset Arduino

    if(cont_rst_sim == 2){
      Serial.println(F("Begin DATA after reset"));
      state = DATOS;
      remove_msg();
      //Serial.println(ciclo);
    }
    if(cont_rst_sim >= 3){
      state = RESET_ARDU;
      break;
    }
    cont_rst_sim++;
    break;
  case RESET_ARDU:
    //Serial.println(F("Reset Arduino"));
    cont_rst_sim = 0;
    digitalWrite(RST_ARD,LOW);
    break;
  case ASK_BAT:
    //Serial.println(F("ASK BATTERY STATE"));
    updateVolt();
    if(vol_bat <= MIN_VOLT_BAT and vol_panel <= MIN_VOLT_PAN){
      //Serial.println(F("LOW BATTERY"));
      state = DORMIR;
      remove_msg();
      break;
    }
    if(last_state == RESET_SIM){
      state = ENVIO;
      last_state = ASK_BAT;
    }else{
      state = DATOS;
    }
    break;  
  default:
    // statements
    break;
  }
  //last_state = state;
}
void remove_msg(){
  //Serial.println(F("REMOVE MSG"));
  ciclo = 0;
  delay(200);
  msg.remove(0,MAX_BYTES); //Se elimina el mensaje enviado
  msg.reserve(MAX_BYTES); //Se vuelve a disponer 290bytes de memoria para el nuevo mensaje
  delay(1000);    
}
void inicializarPines() {
  //Declarar pines de la señal de los sensores efecto hall como inputs
  pinMode(interruptPin, INPUT_PULLUP);
  pinMode(transistor_Pin, OUTPUT);

  //pinMode(DTRpin, OUTPUT);
  //digitalWrite(DTRpin, LOW);
  
  pinMode(hall_an, INPUT); 
  pinMode(hall_pluv1, INPUT);
  
  dht.begin();//Inicializar el DHT
}

void inicializarSM() {
  //Eliminar cualquier alarma previa
  RTC.setAlarm(ALM1_MATCH_DATE, 0, 0, 0, 1);
  RTC.setAlarm(ALM2_MATCH_DATE, 0, 0, 0, 1);
  RTC.alarm(ALARM_1);
  RTC.alarm(ALARM_2);
  RTC.alarmInterrupt(ALARM_1, false);
  RTC.alarmInterrupt(ALARM_2, false);
  RTC.squareWave(SQWAVE_NONE);
}
void updateVolt(){
  vol_bat = uint16_t (analogRead(A1)*(0.0049)*2*100);
  vol_panel = uint8_t (analogRead(A2)*(4.73)*(0.0049)*10);
  //Serial.println(String(vol_bat) + " - " + String(vol_panel));  
}
void tomaDatos() {
  digitalWrite(transistor_Pin, HIGH); //Habilitar nodo 5V de alimentacion sensores
  delay(100);
  
  //Serial.println(F("Comienza Datos"));
  hallCounter = 0;
  hallCounter1 = 0;
  hall(); //Ejecutar funcion para el sensado con los efecto hall (pluviografo y anemometro)
  temp_hum(); //Ejecutar funcion para el sensado de temperatura y humedad

  uint8_t contDifDir = 0;
  uint8_t dirF=0;
  boolean out = true;
  while(out and contDifDir<3){
    uint8_t dir1 = dir();
    delay(1000);
    uint8_t dir2 = dir();
    delay(1000);
    if(dir1 == dir2){
      dirF = dir1;
      out = false;;  
    }else{
      contDifDir++;
      dirF = dir1;
    }
  }  
  delay(1000);
  time_t tiempo = RTC.get();
  //Serial.println(F("Time Datos"));
  //Serial.println((String(hour(tiempo))+ "," + String(minute(tiempo))));
 
  //Guardar datos en un String
  updateVolt();

  finalString.reserve(40); //Se vuelve a disponer 290bytes de memoria para el nuevo mensaje
  finalString = String(day(tiempo))+ "," + String(month(tiempo))+ "," + String(hour(tiempo))+ "," + String(minute(tiempo)) + "," + String(temp) + "," + String(h) + "," + String(hallCounter) + "," + String(dirF) + "," + String(hallCounter1) + "," + String(vol_panel) + "," + String(vol_bat)+";";
  
  if(first_run){
    finalString = String(day(tiempo))+ "," + String(month(tiempo))+ "," + String(hour(tiempo))+ "," + String(minute(tiempo)) + "," + "-1" + "," + String(h) + "," + String(hallCounter) + "," + String(dirF) + "," + String(hallCounter1) + "," + String(vol_panel) + "," + String(vol_bat) + ";";
    first_run = false;
  }  
  msg = msg + finalString; //Guardar la toma de diferentes ciclos en una variable que sera enviada al servidor
  finalString.remove(0,40); //Se elimina el mensaje enviado
  Serial.println(msg);
  
  digitalWrite(transistor_Pin, LOW); //Desabilitar nodo 5V de alimentacion sensores
  delay(100);
}

void hall() {
  hallCounter = 0;
  hallCounter1 = 0;
  starttime = millis();
  new_endtime = millis();
  //Serial.println(F("Init Hall"));
  
  while ((new_endtime - starttime) < 60000) { //Realizar este loop durante 45 segundos
//    Serial.println((new_endtime - starttime));
//    Serial.println(F("Inside"));
    hallState = digitalRead(hall_an); //Estado hall anemometro
    hallState1 = digitalRead(hall_pluv1); //Estado hall pluviografo 1
//    if (hallState == HIGH) {
//      Serial.println("HIGH");
//    }else{
//      Serial.println("LOW");
//    }
    //Si hay un cambio en el estado HIGH ->LOW o LOW->HIGH en la señal de salida de los efecto hall
    //se aumenta en 1 el numero de tic tocs
    if (lLLastHall != lLastHall) { 
      if (hallState == HIGH and lastHall == HIGH and lLastHall == HIGH) {
        hallCounter++;
        Serial.println(hallCounter);
      }
      delay(10);
    }
    if (lLLastHall1 != lLastHall1) {
      if (hallState1 == HIGH and lastHall1 == HIGH and lLastHall1 == HIGH) {
        hallCounter1++;
        Serial.println(hallCounter1);
      }
      delay(10);
    }
    
    lLLastHall = lLastHall;
    lLastHall = lastHall;
    lastHall = hallState;

    lLLastHall1 = lLastHall1;
    lLastHall1 = lastHall1;
    lastHall1 = hallState1;

    
    new_endtime = millis();   
  }
//  Serial.println("Counter"); 
//  Serial.println(hallCounter);
//  Serial.println(hallCounter1);  
}

void temp_hum() {
  h = uint8_t(dht.readHumidity()); //Leer la humedad relativa
  temp = uint16_t(10 * dht.readTemperature()); //Leer temperatura en grados Celsius
  //Serial.println("Datos Ambiente");
  //Serial.println(String(h) + " - " + String(temp));
}
uint8_t dir(){

  //Dependiendo del valor analogo obtenido de la señal del sensor infrarrojo se establece la direccion
    WV = analogRead(A3);
    //Serial.println("DIR ->");
    //Serial.println(WV);
    uint8_t direccion;

    if (WV > 145 && WV < 165){
      direccion = 1;
    }
    else if (WV >= 166 && WV < 180){
      direccion = 2;
    }
    else if (WV >= 181 && WV < 200){
      direccion = 3;
    }
    else if (WV >= 201 && WV < 220){
      direccion = 4;
    }
    else if (WV >= 221 && WV < 246){
      direccion = 5;
    }  
    else if (WV >= 246 && WV < 275){
      direccion = 6;
    }
    else if (WV >= 276 && WV < 305){
      direccion = 7;
    }
    else if (WV >= 305 && WV < 413){
      direccion = 8;
    }
    else{
      direccion = 9;
    }

    //Serial.println(direccion);
    return direccion;
}
void Going_To_Sleep() {
    Serial.println(F("GOINGTOSLEEP"));

    RTC.begin();
    //Eliminar cualquier alarma previa
    RTC.setAlarm(ALM1_MATCH_DATE, 0, 0, 0, 1);
    RTC.setAlarm(ALM2_MATCH_DATE, 0, 0, 0, 1);
    RTC.alarm(ALARM_1);
    RTC.alarm(ALARM_2);
    RTC.alarmInterrupt(ALARM_1, false);
    RTC.alarmInterrupt(ALARM_2, false);
    
    RTC.squareWave(SQWAVE_NONE);
    
    //Serial.println((String(hour(t))+ "," + String(minute(t))));
    time_t t = RTC.get();
    if(first_init == true){
      last_wake_up_min = minute(t);
      last_wake_up_hour = hour(t);
      first_init = false;
    }
    
    wake_up_min = last_wake_up_min + time_interval;
    wake_up_hour = last_wake_up_hour;
    if (wake_up_min >= 60){
      wake_up_min =  wake_up_min - 60;
      wake_up_hour += 1;
    }
    if(wake_up_hour == 24){
      wake_up_hour = 0;
    }
    last_wake_up_min = wake_up_min;
    last_wake_up_hour = wake_up_hour;
    
    bool incorrect_alarm = false;
    if(hour(t)==wake_up_hour){
        if(minute(t) >= wake_up_min){
          incorrect_alarm = true;
        }
      }
      else if(hour(t)>wake_up_hour){
        incorrect_alarm = true;
      }
    
    if(incorrect_alarm){
      //Serial.println(F("Incorrect Alarm"));
      wake_up_min = minute(t) + time_interval;
      wake_up_hour = hour(t);
      if (wake_up_min >= 60){
        wake_up_min =  wake_up_min - 60;
        wake_up_hour += 1;
      }
      if(wake_up_hour == 24){
        wake_up_hour = 0;
      }
      last_wake_up_min = wake_up_min;
      last_wake_up_hour = wake_up_hour;
    }
    
    //Serial.println(String(wake_up_hour) + " - " + String(wake_up_min));
    boolean correct_wakeup = false;
    while(correct_wakeup==false){
      RTC.setAlarm(ALM1_MATCH_HOURS , 0, wake_up_min, wake_up_hour, 0); //Poner nueva alarma
      RTC.alarm(ALARM_1);
      RTC.alarmInterrupt(ALARM_1, true);  //Habilitar interrupcion de "ALARM_1"
      
  
      pinMode(interruptPin, INPUT_PULLUP);
      delay(100);
      sleep_enable();//Habilitar sleep mode
      attachInterrupt(digitalPinToInterrupt(interruptPin), wakeUp, LOW); //Adjuntar la interrupcion al pin D2
  
      set_sleep_mode(SLEEP_MODE_PWR_DOWN);//Modo full sleep
      delay(1000); 
      sleep_cpu();//Activar sleep mode
      
      //Next Line after wakeup
      //Serial.println(F("GOINGTOSLEEP_AWAKE"));
      delay(1000);
      time_t t1 = RTC.get();
      //Serial.println(String(hour(t1))+ " - " + String(minute(t1)));
      
      if(hour(t1)==wake_up_hour){
        if(minute(t1) >= wake_up_min){
          correct_wakeup = true;
        }
      }
    }
}

void wakeUp() {
  //Serial.println(F("Interrrupt Fired"));
  sleep_disable();//Deshabilitar sleep mode
  detachInterrupt(0); //Eliminar la interrupcion del pin 2;
}

void eliminarUltimoDigitoURL(){
  //Serial.println(msg);
  //Serial.println(F("BORRAR ULTIMO ADD URL"));
  msg = URL + msg;
  
  len = msg.length();
  msg.remove(len-1);
  //Serial.println(msg);
  delay(2000);
}
bool sendGet(String msg_param) {
    // Setup module for GPRS communication
  bool enviado = false; 
  uint8_t contfail = 0;
  uint8_t contFailSetup = 0;
    
  while(!enviado and contfail<5){
    boolean var1;
    contFailSetup = 0;
    while(contFailSetup <= 2){
      var1 = setupModule();
      if(!var1){
        contFailSetup++;
        Serial.println(F("Failed setup cycle"));
        Serial.println(var1);
        Serial.println(F("Reset SIM"));
//        sim800l->reset();
//        delay(5000); 
      }else{
        break;
      }
    }
//    if(var1 == false){
//      Serial.println(F("Var False"));
//    }else{
//      Serial.println(F("Var TRUE"));
//    }
    if(contFailSetup>=4 and !var1){
      Serial.println(F("Unable to Setup Module SIM"));
      //return false;
    }
//    // Close GPRS connectivity (5 trials)
//    bool disconnected2 = sim800l->disconnectGPRS();
//    for(uint8_t i = 0; i < 2 && !disconnected2; i++) {
//      delay(1000);
//      disconnected2 = sim800l->disconnectGPRS();
//    }
//    
//    if(disconnected2) {
//      Serial.println(F("GPRS disconnected !"));
//    } else {
//      Serial.println(F("GPRS still connected !"));
//    }
    
    // Establish GPRS connectivity (5 trials)
    bool connected = false;
    for(uint8_t i = 0; i < 2 && !connected; i++) {
      delay(2000);
      connected = sim800l->connectGPRS1();
    }
  
    // Check if connected, if not reset the module and setup the config again
    if(!connected) {
      Serial.println(F("GPRS1 not connected !"));
    }
      
    connected = false;
    for(uint8_t i = 0; i < 5 && !connected; i++) {
      delay(1000);
      connected = sim800l->connectGPRS2();
    }
  
    // Check if connected, if not reset the module and setup the config again
    if(connected) {
      Serial.println(F("GPRS2 connected !"));
    } else {
      Serial.println(F("GPRS2 not connected !"));
    }
    delay(5000);
    Serial.println(F("Start HTTP GET..."));
  
    connected = false;
    for(uint8_t i = 0; i < 5 && !connected; i++) {
      delay(1000);
      connected = sim800l->initiateHTTPINIT();
    }
  
    // Check if connected, if not reset the module and setup the config again
    if(!connected) {
      Serial.println(F("HTTP FAIL !"));
    }
    Serial.println(F("URL HTTP"));
    Serial.println(msg_param);
    connected = false;
    for(uint8_t i = 0; i < 5 && !connected; i++) {
      delay(5000);
      connected = sim800l->initiateHTTPPARAINIT((msg).c_str(),NULL);
    }
  
    // Check if connected, if not reset the module and setup the config again
    if(connected) {
      Serial.println(F("HTTPPARA SUCCESS !"));
    } else {
      Serial.println(F("HTTPPARA FAIL !"));
    }

    uint16_t contHttpError = 0;
    while(enviado==false and contHttpError < 3){
      // Do HTTP GET communication with 10s for the timeout (read)
      uint16_t rc = sim800l->doGet(65000);
       if(rc == 200 or rc == 409) {
        // Success, output the data received on the serial
        Serial.println(F("HTTP GET successful"));
        enviado = true;
        break;
      } else {
        // Failed...
        Serial.print(F("HTTP GET error "));
        Serial.println(rc);
        contHttpError++;
        delay(3000);
//        Serial.println("ContFail");
//        Serial.println(contfail);
      }
    }
    delay(1000);
    // Close GPRS connectivity (5 trials)
    bool disconnected = sim800l->disconnectGPRS();
    for(uint8_t i = 0; i < 2 && !connected; i++) {
      delay(1000);
      disconnected = sim800l->disconnectGPRS();
    }
    
    if(!disconnected) {
      Serial.println(F("GPRS still connected !"));
    }
    delay(5000);
    // Go into low power mode
    bool lowPowerMode = sim800l->setPowerMode(MINIMUM);
    if(!lowPowerMode) {
      Serial.println(F("Failed to switch module to low power mode"));
      delay(500);
      lowPowerMode = sim800l->setPowerMode(MINIMUM);
      if(!lowPowerMode) {
        Serial.println(F("Failed to switch module to low power mode x2"));
      }
    }
    
    delay(5000);
    // Go into sleep mode
    lowPowerMode = sim800l->sleepModeCLK();
    if(!lowPowerMode) {
      Serial.println(F("Failed to switch module to sleep mode"));
    }
    contfail++;
//    Serial.println(F("ContFail"));
//    Serial.println(contfail);

  }
  return enviado;
}

bool setupModule() {
  bool resp = true;
  uint8_t maxContSig = 0;
    // Wait until the module is ready to accept AT commands
  while(!sim800l->isReady() and maxContSig < LIMIT_CONT) {
    //Serial.println(F("Problem to initialize AT command, retry in 1 sec"));
    delay(500);
    maxContSig++;
  }
  if(maxContSig>=LIMIT_CONT){
    Serial.println(F("No AT Response"));
    return false;
  }
  delay(500);
  if(sim800l->sleepWakeCLK()) {
    //Serial.println(F("Module awake mode"));
  } else {
    Serial.println(F("Failed to wake up module"));
  }
  
  Serial.println(F("Setup Complete!"));
  bool nornmalMode = sim800l->setPowerMode(NORMAL);
//  if(nornmalMode) {
//    Serial.println(F("Module in normal power mode"));
//  } else {
//    Serial.println(F("Failed to switch module to normal power mode"));
//  }
  // Wait for the GSM signal
  maxContSig = 0;
  uint8_t signal = sim800l->getSignal();
  while(signal <= 0 && maxContSig < LIMIT_CONT) {
    delay(500);
    signal = sim800l->getSignal();
    Serial.print(signal);
    maxContSig++;
  }
  if(maxContSig>=LIMIT_CONT){
    Serial.println(F("No Signal"));
    resp = false;
  }
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

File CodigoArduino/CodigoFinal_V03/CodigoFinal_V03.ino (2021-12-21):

#include "Arduino.h"
#include "DHT.h" // Libreria DHT de Adafruit para DHT 11 o DHT 22 https://github.com/adafruit/DHT-sensor-library/archive/master.zip
#include "SIM800L.h"
#include <ESP32Time.h>
#include "PCF8574.h"

#include <driver/adc.h>

#include <EEPROM.h>
#include <WiFi.h>
#include <BluetoothSerial.h>
#include <esp_bt.h>


// Set i2c address
PCF8574 pcf8574(0x20);

#define hall1_vel 25   //Pin del transistor
#define hall2_vel 26   //Pin del transistor

// ---------------------- PLUVIOGRAFO -------------
#define HALL_PLUVI 27

uint8_t hallCounter = 0;   //Contador tic tocs anemometro
uint8_t hallState = 0;         //Estado actual del sensor efecto hall anemometro (HIGH,LOW)
uint8_t lastHall = 0;     //Estado previo del sensor efecto hall anemometro (HIGH,LOW)
uint8_t lLastHall = 0;     //Estado previo del sensor efecto hall anemometro (HIGH,LOW)
uint8_t lLLastHall = 0;     //Estado previo del sensor efecto hall anemometro (HIGH,LOW)

uint8_t hallCounter1 = 0;   //Contador tic tocs ´pluviografo
uint8_t hallState1 = 0;      //Estado actual del sensor efecto hall pluviografo (HIGH,LOW)
uint8_t lastHall1 = 0;    //Estado previo del sensor efecto hall pluviografo (HIGH,LOW)
uint8_t lLastHall1 = 0;     //Estado previo del sensor efecto hall anemometro (HIGH,LOW)
uint8_t lLLastHall1 = 0;     //Estado previo del sensor efecto hall anemometro (HIGH,LOW)

unsigned long tiempo_hall = 45000;

//---------------------- RTC ----------------------
ESP32Time rtc;

String time_str = "";
//---------------------- END RTC ----------------------

//const char APN[] = "hologram";
const char APN[] = "pepper";
const char USR[] = "comcel";
const char URL[] = "http://eco.agromakers.org/api/r_v?id=2020080427&tramo=";
const char URL2[] = "http://eco.agromakers.org/api/date";

SIM800L* sim800l;

//------------------ END HALL --------------

//---------- MOSFETs ---------------
#define transistor_sen 15   //Pin del transistor
#define transistor_sim 33   //Pin del transistor
#define transistor_aux 32   //Pin del transistor

//---------------- SLEEP MODE & RTC ---------------
//Variables 
//Variables de tiempo para el sensado del anemometro y el pluviografo
unsigned long starttime;
unsigned long new_endtime = 0;
int len;

//Numero de tomas y Sleep Mode
#define interruptPin 2 //Pin de interrupcion para despertar el arduino

const uint8_t time_interval = 1; //Intervalo de tiempo para la toma de datos
const uint8_t num_ciclos = 8; //Definir numero de tomas previas al envío (tomar 6 como valor máximo para evitar problemas de inestabilidad)

RTC_DATA_ATTR uint8_t ciclo = 0; 

#define uS_TO_S_FACTOR 1000000  /* Conversion factor for micro seconds to seconds */
#define TIME_TO_SLEEP  900        /* Time ESP32 will go to sleep (in seconds) */

#define maxRecords 8 // Nombre max enregistrements

RTC_DATA_ATTR int bootCount = 0;

//----------------END SLEEP MODE & RTC ---------------


// ---------------- ESTADOS -------------
//Estado
uint8_t state = 1;
uint8_t last_state = 1;
  
const uint8_t DORMIR PROGMEM = 2;
const uint8_t DATOS PROGMEM = 1;
const uint8_t ENVIO PROGMEM = 3;
const uint8_t RESET_SIM PROGMEM = 5;
const uint8_t RESET_ARDU PROGMEM = 6;
const uint8_t ASK_BAT PROGMEM = 7;
const uint8_t INIT PROGMEM = 0;

const uint16_t MIN_VOLT_BAT = 345;
const uint8_t MIN_VOLT_PAN = 900;

boolean wait = false;

const uint8_t LIMIT_CONT = 35;


// ------------------ END ESTADOS -------------
// --------------SYSTEM VARIABLES -------------
//Outputs
//Strings en donde se almacenan los datos tomados
String finalString;

String msg;

boolean first_init = true;
boolean first_run = true;

int vol_bat;
int vol_panel; 

uint8_t cont_rst_sim = 0;

#define RST_ARD 4

const uint16_t MAX_BYTES = 500;

typedef struct {
  uint8_t Dia;
  uint8_t Mes;
  uint8_t Hora;
  uint8_t Minuto;

  uint8_t Dir;
  uint8_t Vel;
  uint8_t Pluv;
  uint16_t Temp;
  uint16_t Hum;

  uint16_t Panel;
  uint16_t Bateria;
} bmp180Records;


RTC_DATA_ATTR bmp180Records Records[maxRecords];

// --------------END SYSTEM VARIABLES -------------


#define PIN_BAT 36
#define PIN_PANEL 39



// ----------- RGB ---------------

// Set up the rgb led names
uint8_t ledR = 19;
uint8_t ledG = 18;
uint8_t ledB = 5; 

uint8_t ledArray[3] = {1, 2, 3}; // three led channels

const boolean invert = true; // set true if common anode, false if common cathode

uint8_t color = 0;          // a value from 0 to 255 representing the hue
uint32_t R, G, B;           // the Red Green and Blue color components
uint8_t brightness = 255;  // 255 is maximum brightness, but can be changed.  Might need 256 for common anode to fully turn off.

// --------------------- DHT ---------------------
#define DHTPIN 13     //Pin donde está conectado el sensor DHT
#define DHTTYPE DHT22   //Sensor DHT22
DHT dht(DHTPIN, DHTTYPE);
uint8_t h;  //Variable de humedad relativa (0-100)
uint16_t temp; //Variable temeperatura grados centigrados



//Que se cuenten envios de rrores pero que siga los siguientes estados. Reset cuando hallan 3 mensajes que no se han enviado.
void setup() {
  // Initialize Serial Monitor for debugging
  Serial.begin(9600);
  Serial2.begin(57600);
  while(!Serial);
  delay(500);

  initRGB();

  led_verde(5,1000);
  
  setModemSleep();

  Serial.print(F("Ciclo Numero "));
  Serial.println(ciclo);

  if(revisar_bat()){
    init_setup();
    if(bootCount==0){
      Serial.println(F("FIRST RUN"));
      led_verde(10,500);
      update_time();
      init_RTC_memory();
      state = INIT;  
    }else{
      state = DATOS;
    }
    ++bootCount;
    Serial.println("Boot number: " + String(bootCount));
  
    //Print the wakeup reason for ESP32
    print_wakeup_reason();
  
    esp_sleep_enable_timer_wakeup(TIME_TO_SLEEP * uS_TO_S_FACTOR);
    Serial.println("Setup ESP32 to sleep for every " + String(TIME_TO_SLEEP) + " Seconds"); 
  }else{
    state = DORMIR;
  }
  
  while(true){
    loop_edited();
  }
}
void init_sensors(){

  digitalWrite(transistor_aux, HIGH); //Habilitar nodo 5V de alimentacion sensores
  digitalWrite(transistor_sen, HIGH); //Habilitar nodo 5V de alimentacion sensores

  delay(5000);

  pinMode(hall1_vel, INPUT_PULLUP);
  pinMode(hall2_vel, INPUT_PULLUP);
  
  pcf8574.pinMode(P0, INPUT_PULLUP);
  pcf8574.pinMode(P1, INPUT_PULLUP);
  pcf8574.pinMode(P2, INPUT_PULLUP);
  pcf8574.pinMode(P3, INPUT_PULLUP);
  pcf8574.pinMode(P4, INPUT_PULLUP);
  pcf8574.pinMode(P5, INPUT_PULLUP);
  pcf8574.pinMode(P6, INPUT_PULLUP);
  pcf8574.pinMode(P7, INPUT_PULLUP);

  Serial.print("Init pcf8574...");
  if (pcf8574.begin()){
    Serial.println("OK");
  }else{
    Serial.println("KO");
  }

 dht.begin();//Inicializar el DHT

 pinMode(HALL_PLUVI, INPUT); 

 delay(5000);
 
 digitalWrite(transistor_aux, LOW); //Habilitar nodo 5V de alimentacion sensores
 digitalWrite(transistor_sen, LOW); //Habilitar nodo 5V de alimentacion sensores
}
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

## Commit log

2020-04-06 Cambio PCB Devolucion China
    [Base.0001.ipt, Base.ipt, BaseHumedadDireccion - copia.ipt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]
2020-04-16 Se agrego ultima version PCB
    [DoubLayerSim.kicad_pcb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]
2020-04-22 Programa que incluye toma de datos, subida al servidor y sleep mode del SIM800L
2020-04-23 Organización de carpetas de PCB
    [DoubLayerSim.kicad_pcb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]
2020-04-25 Cambiando imagen de arduino
2020-04-25 imagen arduino
2020-04-25 Imagenes de diagramas
2020-04-25 Imagenes PCBs
2020-04-28 Adelanto diseños
    [Direccion.0001.ipt, Direccion.0001_1.ipt, Direccion.0002.ipt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]
2020-05-04 Programa que incluye toma de datos, subida al servidor, sleep mode por medio del modulo RTC y sleep mode del SIM800L
2020-06-29 Cambio 3D
    [ConexionDireccionTop.0001.ipt, ConexionDireccionTop.ipt, ConexionDireccionTop.stl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]
2020-06-29 Se movieron editables a PROYECTO_GIT
    [Base Anemometro.stl, Base.0001.ipt, Base.ipt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]
2020-08-21 Programa que incluye toma de datos, envío al servidor, sleep mode por medio del modulo RTC y sleep mode del SIM800L
2020-10-17 Crear Datalogger_Final.ino
    Se creó el archivo con el programa final, en el que satisfactoriamente se sensan y se suben al servidor las variables de interés, haciendo uso del sleep mode.
2021-02-24 Prueba Sensores, Basic SIM800L and CodigoFinalProbado
    [Base.0001.ipt, Base.0006.ipt, Base.ipt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]
2021-03-06 CodigoFinal Protocolos,Sleep Mode, Minimum power mode
2021-04-28 Actualizacion Codigo Arduino
2021-06-15 Update 15 JUN
    [DoubLayerSim.sch, PCB_BatteryCharger.kicad_pcb]
